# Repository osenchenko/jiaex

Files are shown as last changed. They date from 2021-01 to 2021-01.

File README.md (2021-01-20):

#  JiaEX - split keyboard for extended alphabets.

`assembled-keyboard.stl` - 3d model of assembled keyboard.

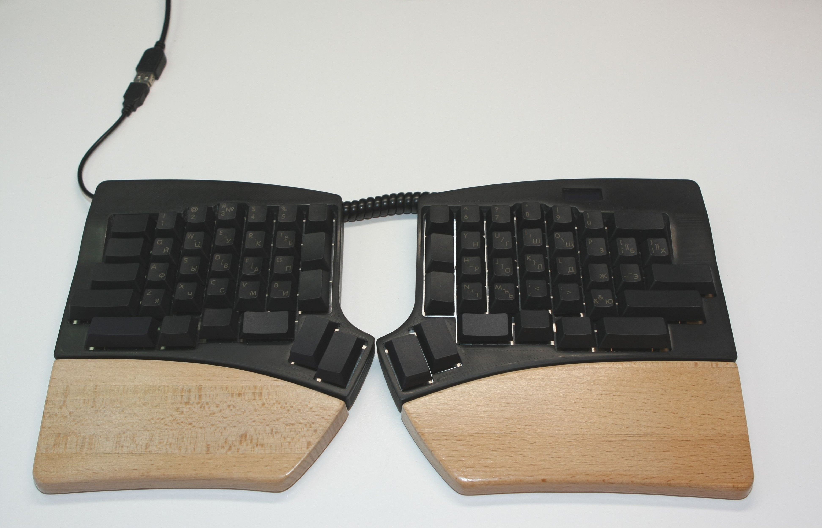
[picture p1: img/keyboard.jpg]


## Features

- enough keys for placing on base layer all letters for extended alphabets (alphabets with more than 26 letters).
- plenty of keys for playing with different variants to find your best setup.
- one keyboard for all operating systems. Switch between settings for different operating systems with a shortcut (currently settings for Linux and Windows are implemented).
- used AT90USB1286 with 128 KB memory. No limits for storing settings.
- wide choice of keycaps. The keyboard is designed for maximum use of keycap sets from standard keyboards. 1.75U keys of thumb cluster and 1.5U vertical keys can be replaced with 1.5U or 1.25U keys in any combination.
- wrist pad is rigidly attached to the keyboard. The keyboard is not intended to be used without a wrist pad.
- the display shows current default layout (for example Linux) and current active layer plus Caps Lock state.
- powered by QMK.

## Layout

[keyboard-layout-editor.com](http://www.keyboard-layout-editor.com/#/gists/80bbde035c246cb868fec8fd4ef6ad40)

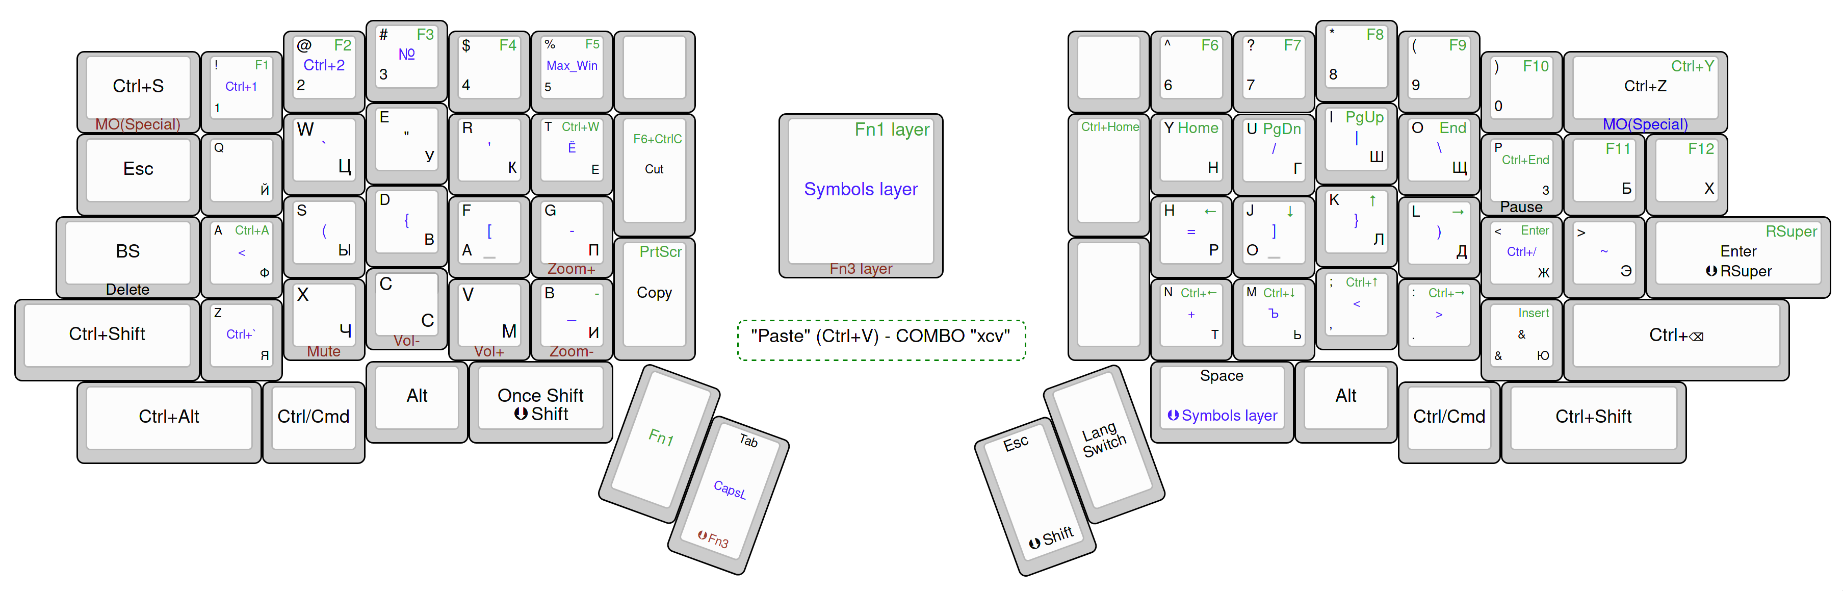
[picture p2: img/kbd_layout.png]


## Build guide

### Folders

- `case` - stl-files for 3d printing case and wrist pads. <br/>Case and wrist pads are designed by Alexander_St enginemojo@gmail.com.
- `datasheets` - datasheets for some used parts
- `firmware` - source files for QMK firmware
- `pcb` - KiCAD source and gerber files for manufacturing PCB.
- `plate` - dxf for laser cutting metal plate.

### Firmware

- install qmk 
- copy folder `jiaex` from `firmware` to `keyboards` folder of qmk installation
- <u>Until pull request [#11487](https://github.com/qmk/qmk_firmware/pull/11487) is not merged in QMK master you must apply this pull request by yourself.</u>
- run `qmk flash -kb jiaex -km default` 

### PCB and Case

Kicad libraries used:

- https://github.com/XenGi/teensy_library

### Bill of materials

| Name | Value | Quantity |
| --- | --- | ---: |
| Microcontroller board | [Teensy ++ 2.0](https://www.pjrc.com/store/teensypp.html) | 2 |
| SMD Diode | 1N4148 [SOD-123] | 68 |
| SMD Resistor 1206 | 30K | 2 |
| SMD Resistor 1206 | 3K | 4 |
| SMD Resistor 1206 | 10K | 1 |
| Jack RJ-22 | [215875-1, Conn RJ-22 F 4 POS 1.02mm Solder RA Thru-Hole 4 Terminal 1 Port Cat 3 T/R](datasheets/Jack_RJ-22.pdf) | 2 |
| OLED display | [0.91 inch OLED Module 128x32, I2C](datasheets/OLED_Module_User_Manual_EN.pdf) | 1 |
| Plug for OLED display | [PLS-4R (DS1022-1x4R)](datasheets/DS1022.pdf) | 1 |
| Key switch | Any Cherry MX compatible | 68 |
| Key stabilyzers | Any Cherry MX compatible, plate mount | 6 |
| 4-wire phone cable with RJ11 (TP-4P4C) jacks. | Max length of cable - 11 cm. | 1 |
| Rubber feet | At your own choice. I use [RF-3004](datasheets/DOC004505728.pdf) | --- |
| Metal plate. Thickness | 1.5 mm | 2 |

### Screws

| Name | Diameter, mm | Length, mm | Image | Quantity | Notes |
| --- | ---: | ---: | --- | ---: | --- |
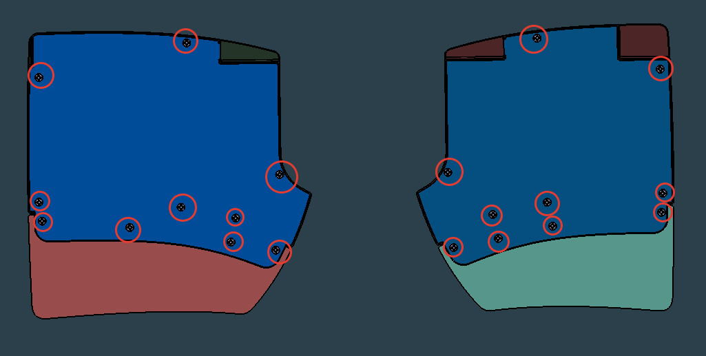
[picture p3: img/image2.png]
| Self-tapping screw for plastic, countersunk head, blunt end, Phillips head, full thread, ART 9090 | 3 | 8..10 |  | 20 | Drill the hole with a 2 mm drill before insert screw. |
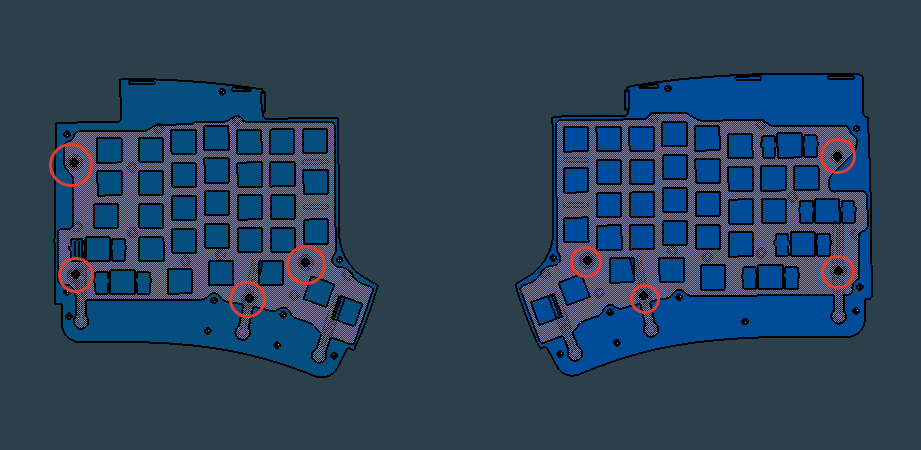
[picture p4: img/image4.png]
| Self-tapping screw DIN 7981 FH (A2) with a blunt end with a half-cylindrical head, head Phillips ST2.2 | 2.2 | 6.5..8 |  | 8 | Drill the hole with a 1.2 mm drill before insert screw. |

## Inspiration

Keyboard is inspired by the following keyboards:

- Jian
- Jiran
- Ultimate Hacking Keyboard
- Ergodox

Layout inspired by ideas of:

- Tonsky https://tonsky.livejournal.com/318571.html (for non-Russian speakers use google translate  in Chrome browser)
- Ultimate Hacking Keyboard
- Optozorax https://github.com/optozorax/moonlander (for non-Russian speakers use google translate in Chrome browser)

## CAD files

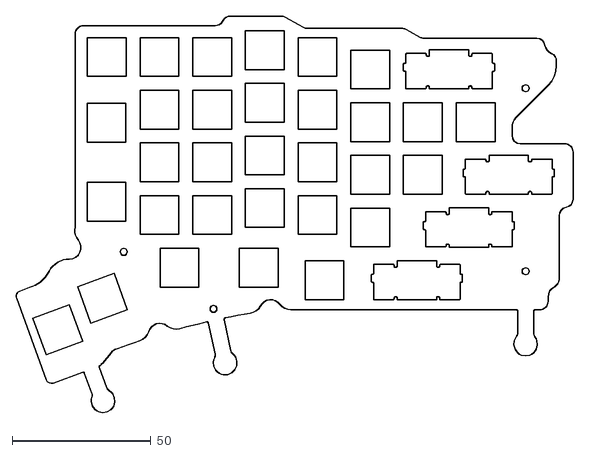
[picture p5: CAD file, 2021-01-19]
plate/RIGHT_Metall_plate.dxf
201.0 x 143.6

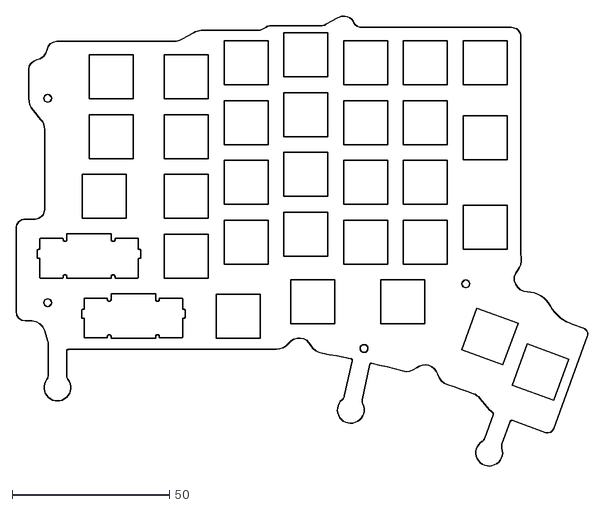
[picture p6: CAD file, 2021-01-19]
plate/LEFT_Metall_plate.dxf
182.0 x 143.6

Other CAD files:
case/left/LEFT_WRIST_PAD.stl
case/right/RIGHT_WRIST_PAD.stl

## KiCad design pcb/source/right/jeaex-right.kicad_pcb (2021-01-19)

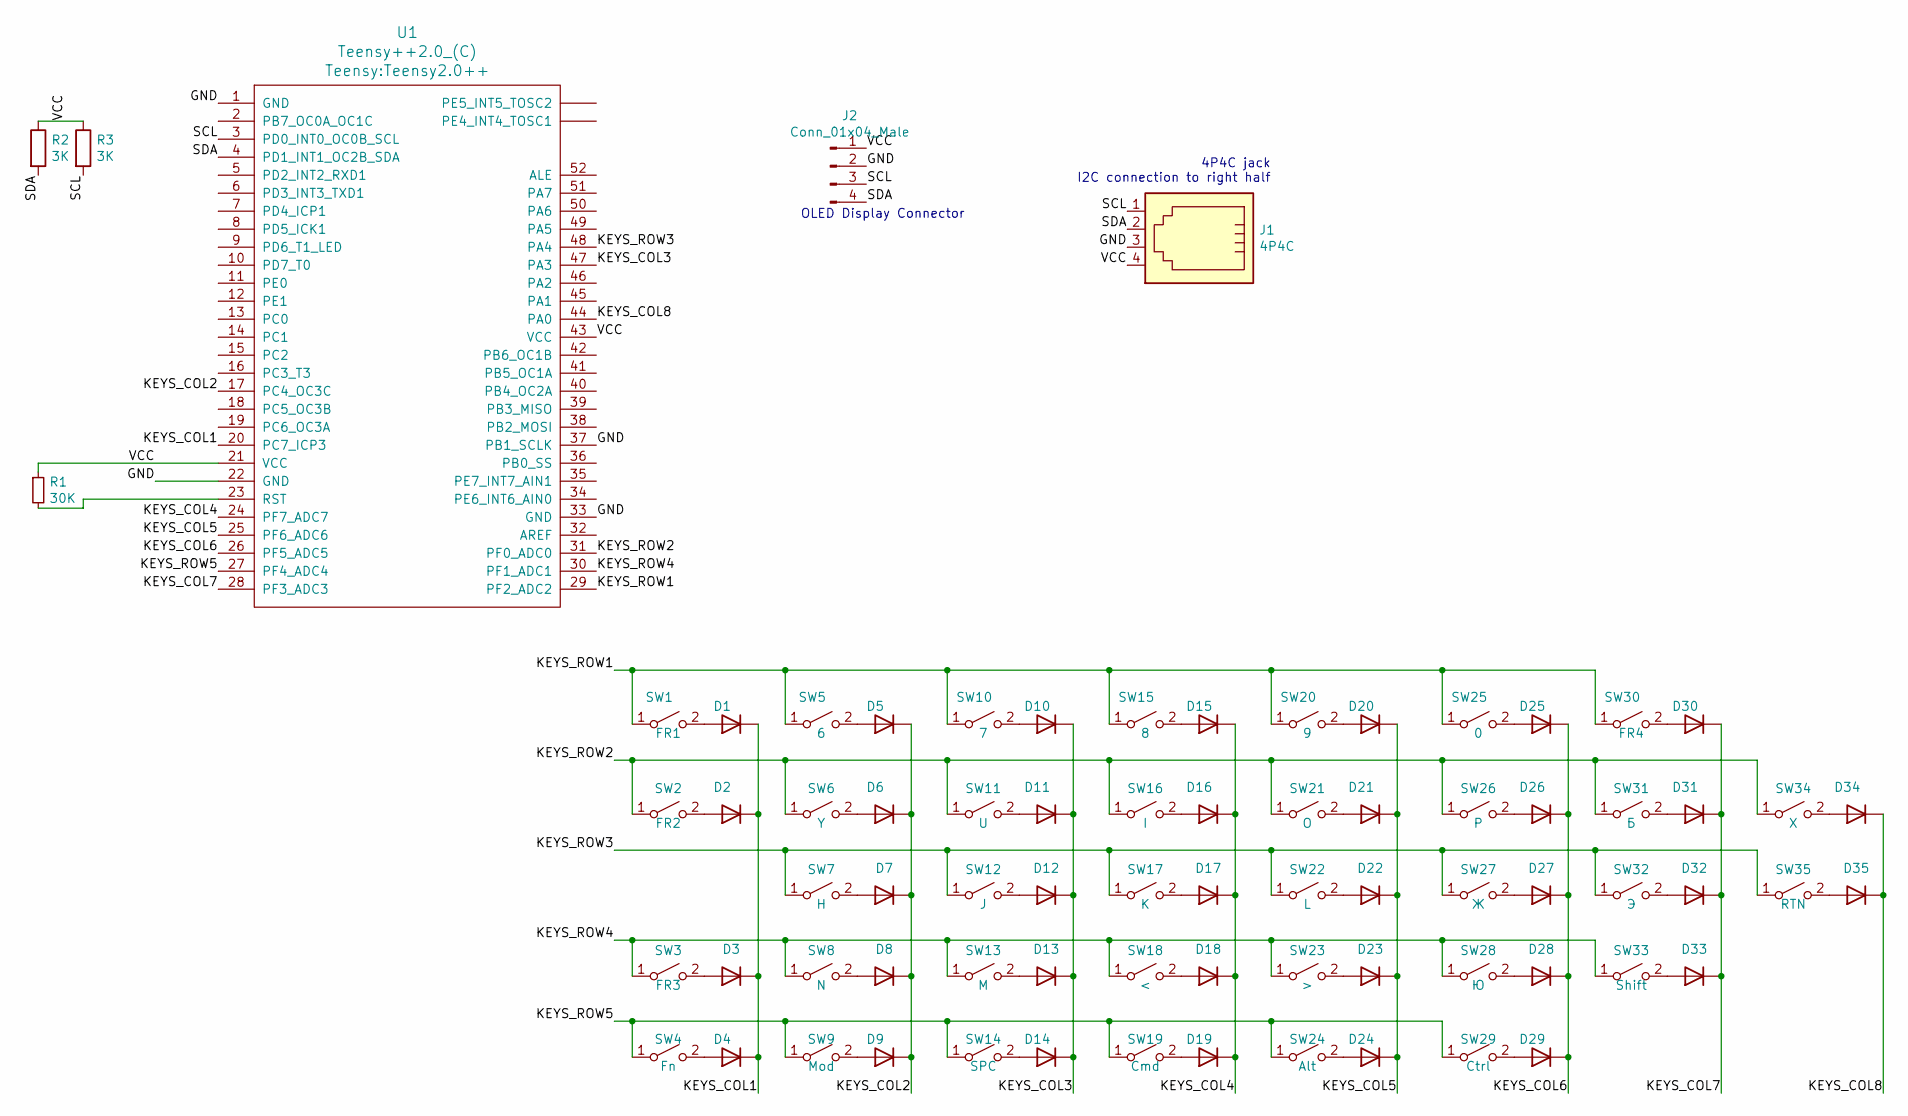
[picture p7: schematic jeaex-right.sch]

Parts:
D1, D2, D3, D4, D5, D6, D7, D8, D9, D10, D11, D12, D13, D14, D15, D16, D17, D18, D19, D20, D21, D22, D23, D24, D25, D26, D27, D28, D29, D30, D31, D32, D33, D34, D35: 1N4148W; D_SOD-123
J1: 4P4C; 4P4C_Jack_0955012441
J2: Conn_01x04_Male; PinHeader_1x04_P2.54mm_Vertical
R1: 30K; R_1206_3216Metric_Pad1.30x1.75mm_HandSolder
R2, R3: 3K; R_1206_3216Metric_Pad1.30x1.75mm_HandSolder
SW1: FR1; SW_Cherry_MX_1.00u_Plate
SW2: FR2; SW_Cherry_MX_1.50u_Plate
SW3: FR3; SW_Cherry_MX_1.50u_Plate
SW4: Fn; SW_Cherry_MX_1.75u_Plate
SW5: 6; SW_Cherry_MX_1.00u_Plate
SW6: Y; SW_Cherry_MX_1.00u_Plate
SW7: H; SW_Cherry_MX_1.00u_Plate
SW8: N; SW_Cherry_MX_1.00u_Plate
SW9: Mod; SW_Cherry_MX_1.75u_Plate
SW10: 7; SW_Cherry_MX_1.00u_Plate
SW11: U; SW_Cherry_MX_1.00u_Plate
SW12: J; SW_Cherry_MX_1.00u_Plate
SW13: M; SW_Cherry_MX_1.00u_Plate
SW14: SPC; SW_Cherry_MX_1.75u_Plate
SW15: 8; SW_Cherry_MX_1.00u_Plate
SW16: I; SW_Cherry_MX_1.00u_Plate
SW17: K; SW_Cherry_MX_1.00u_Plate
SW18: <; SW_Cherry_MX_1.00u_Plate
SW19: Cmd; SW_Cherry_MX_1.25u_Plate
SW20: 9; SW_Cherry_MX_1.00u_Plate
SW21: O; SW_Cherry_MX_1.00u_Plate
SW22: L; SW_Cherry_MX_1.00u_Plate
SW23: >; SW_Cherry_MX_1.00u_Plate
SW24: Alt; SW_Cherry_MX_1.25u_Plate
SW25: 0; SW_Cherry_MX_1.00u_Plate
SW26: P; SW_Cherry_MX_1.00u_Plate
SW27: Ж; SW_Cherry_MX_1.00u_Plate
SW28: Ю; SW_Cherry_MX_1.00u_Plate
SW29: Ctrl; SW_Cherry_MX_2.25u_Plate
SW30: FR4; SW_Cherry_MX_2.00u_Plate
SW31: Б; SW_Cherry_MX_1.00u_Plate
SW32: Э; SW_Cherry_MX_1.00u_Plate
SW33: Shift; SW_Cherry_MX_2.75u_Plate
SW34: Х; SW_Cherry_MX_1.00u_Plate
SW35: RTN; SW_Cherry_MX_2.25u_Plate
U1: Teensy++2.0_(C); Teensy2.0++

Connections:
/GND: J1.3, J2.2, U1.1 (GND), U1.22 (GND), U1.33 (GND), U1.37 (PB1_SCLK)
/KEYS_COL1: D1.1 (K), D2.1 (K), D3.1 (K), D4.1 (K), U1.20 (PC7_ICP3)
/KEYS_COL2: D5.1 (K), D6.1 (K), D7.1 (K), D8.1 (K), D9.1 (K), U1.17 (PC4_OC3C)
/KEYS_COL3: D10.1 (K), D11.1 (K), D12.1 (K), D13.1 (K), D14.1 (K), U1.47 (PA3)
/KEYS_COL4: D15.1 (K), D16.1 (K), D17.1 (K), D18.1 (K), D19.1 (K), U1.24 (PF7_ADC7)
/KEYS_COL5: D20.1 (K), D21.1 (K), D22.1 (K), D23.1 (K), D24.1 (K), U1.25 (PF6_ADC6)
/KEYS_COL6: D25.1 (K), D26.1 (K), D27.1 (K), D28.1 (K), D29.1 (K), U1.26 (PF5_ADC5)
/KEYS_COL7: D30.1 (K), D31.1 (K), D32.1 (K), D33.1 (K), U1.28 (PF3_ADC3)
/KEYS_COL8: D34.1 (K), D35.1 (K), U1.44 (PA0)
/KEYS_ROW1: SW1.1 (A), SW5.1 (A), SW10.1 (A), SW15.1 (A), SW20.1 (A), SW25.1 (A), SW30.1 (A), U1.29 (PF2_ADC2)
/KEYS_ROW2: SW2.1 (A), SW6.1 (A), SW11.1 (A), SW16.1 (A), SW21.1 (A), SW26.1 (A), SW31.1 (A), SW34.1 (A), U1.31 (PF0_ADC0)
/KEYS_ROW3: SW7.1 (A), SW12.1 (A), SW17.1 (A), SW22.1 (A), SW27.1 (A), SW32.1 (A), SW35.1 (A), U1.48 (PA4)
/KEYS_ROW4: SW3.1 (A), SW8.1 (A), SW13.1 (A), SW18.1 (A), SW23.1 (A), SW28.1 (A), SW33.1 (A), U1.30 (PF1_ADC1)
/KEYS_ROW5: SW4.1 (A), SW9.1 (A), SW14.1 (A), SW19.1 (A), SW24.1 (A), SW29.1 (A), U1.27 (PF4_ADC4)
/SCL: J1.1, J2.3, R3.2, U1.3 (PD0_INT0_OC0B_SCL)
/SDA: J1.2, J2.4, R2.2, U1.4 (PD1_INT1_OC2B_SDA)
/VCC: J1.4, J2.1, R1.1, R2.1, R3.1, U1.21 (VCC), U1.43 (VCC)
unnamed: D1.2 (A), SW1.2 (B)
unnamed: D2.2 (A), SW2.2 (B)
unnamed: D3.2 (A), SW3.2 (B)
unnamed: D4.2 (A), SW4.2 (B)
unnamed: D5.2 (A), SW5.2 (B)
unnamed: D6.2 (A), SW6.2 (B)
unnamed: D7.2 (A), SW7.2 (B)
unnamed: D8.2 (A), SW8.2 (B)
unnamed: D9.2 (A), SW9.2 (B)
unnamed: D10.2 (A), SW10.2 (B)
unnamed: D11.2 (A), SW11.2 (B)
unnamed: D12.2 (A), SW12.2 (B)
unnamed: D13.2 (A), SW13.2 (B)
unnamed: D14.2 (A), SW14.2 (B)
unnamed: D15.2 (A), SW15.2 (B)
unnamed: D16.2 (A), SW16.2 (B)
unnamed: D17.2 (A), SW17.2 (B)
unnamed: D18.2 (A), SW18.2 (B)
unnamed: D19.2 (A), SW19.2 (B)
unnamed: D20.2 (A), SW20.2 (B)
unnamed: D21.2 (A), SW21.2 (B)
unnamed: D22.2 (A), SW22.2 (B)
unnamed: D23.2 (A), SW23.2 (B)
unnamed: D24.2 (A), SW24.2 (B)
unnamed: D25.2 (A), SW25.2 (B)
unnamed: D26.2 (A), SW26.2 (B)
unnamed: D27.2 (A), SW27.2 (B)
unnamed: D28.2 (A), SW28.2 (B)
unnamed: D29.2 (A), SW29.2 (B)
unnamed: D30.2 (A), SW30.2 (B)
unnamed: D31.2 (A), SW31.2 (B)
unnamed: D32.2 (A), SW32.2 (B)
unnamed: D33.2 (A), SW33.2 (B)
unnamed: D34.2 (A), SW34.2 (B)
unnamed: D35.2 (A), SW35.2 (B)
unnamed: R1.2, U1.23 (RST)

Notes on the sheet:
4P4C jack I2C connection to right half
OLED Display Connector

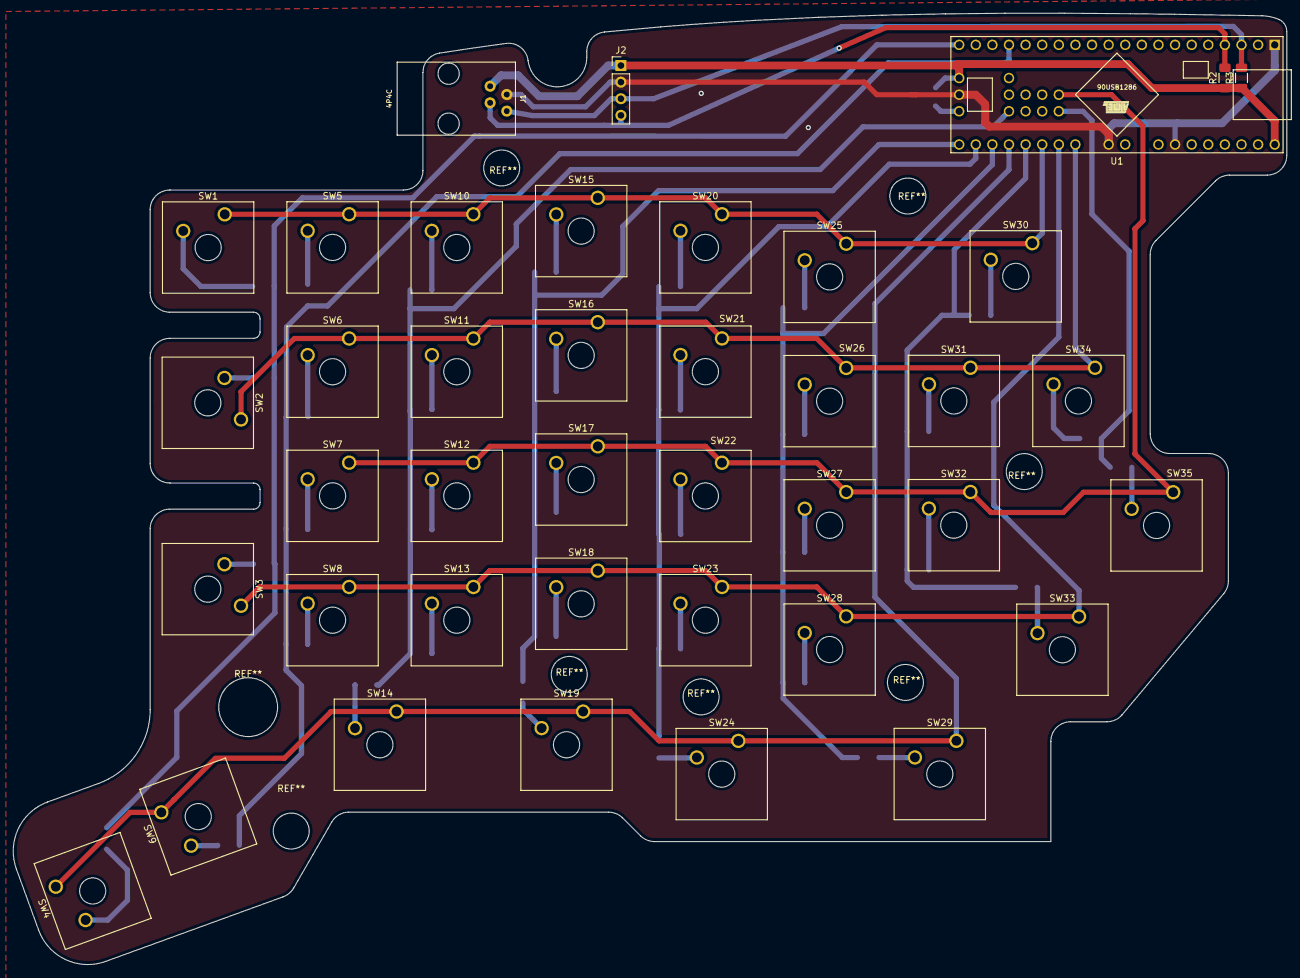
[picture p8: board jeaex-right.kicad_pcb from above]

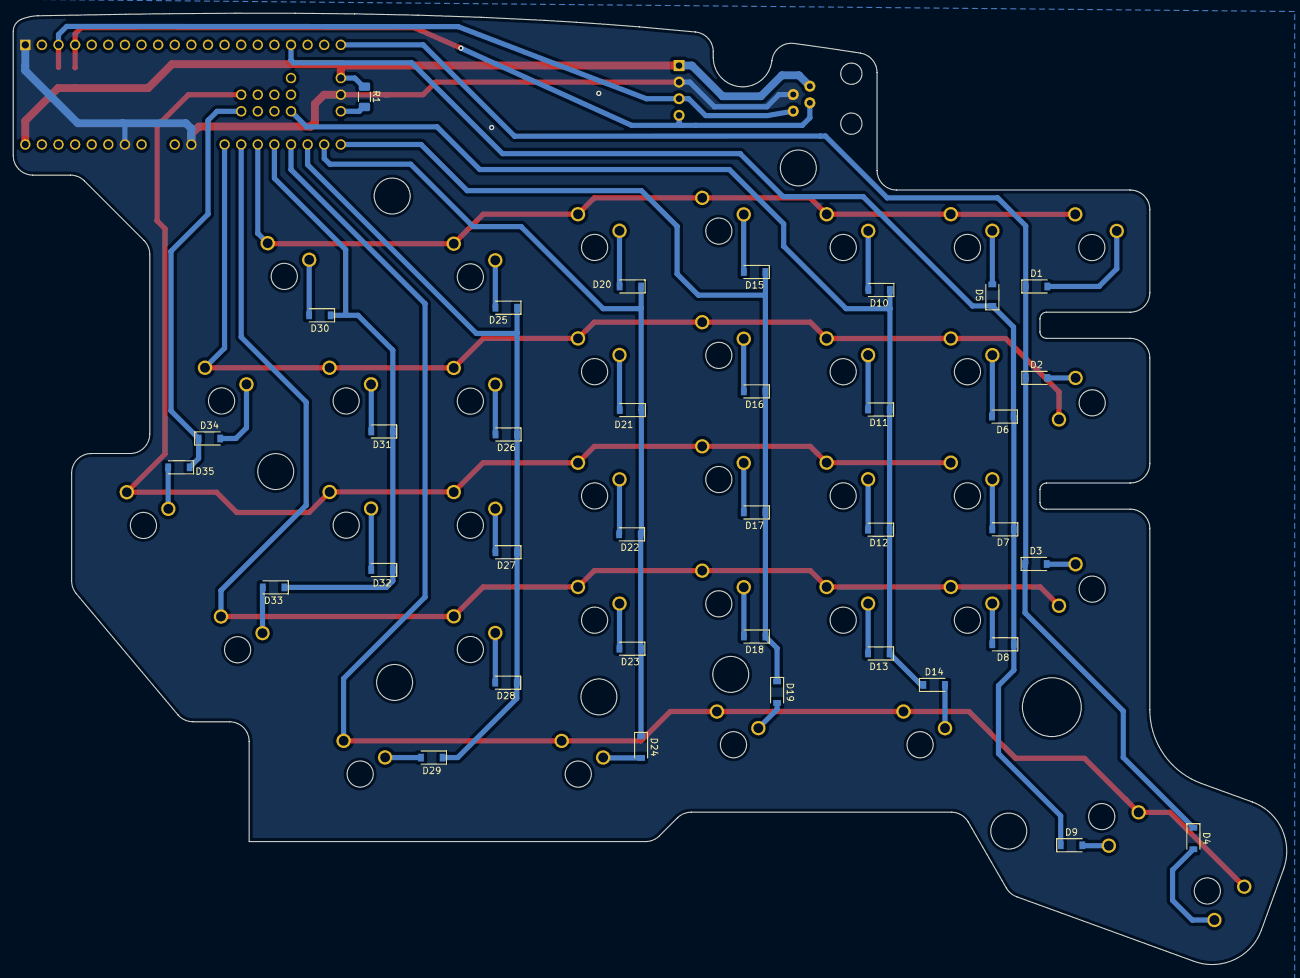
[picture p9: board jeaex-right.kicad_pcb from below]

Board: 2 copper layers, 194.8 x 145.5 mm, 76 parts (36 on the bottom side), 53 nets.

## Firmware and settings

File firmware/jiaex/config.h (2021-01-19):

/*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
You should have received a copy of the GNU General Public License
along with this program.  If not, see <http://www.gnu.org/licenses/>.
*/

#pragma once

#include "config_common.h"

/* USB Device descriptor parameter */
#define VENDOR_ID 0x1209
#define PRODUCT_ID 0x3735
#define DEVICE_VER 0x0001
#define MANUFACTURER Oleg Senchenko
#define PRODUCT JiaEX

/* key matrix size */
// Rows are doubled-up
#define MATRIX_ROWS 10
#define MATRIX_COLS 8

// wiring of each half
#define MATRIX_ROW_PINS \
    { D5, C1, D3, D6, C2 }
#define MATRIX_COL_PINS \
    { D2, D4, E0, C3, C6, C5, C7 }

#define MATRIX_ROW_PINS_RIGHT \
    { F2, F0, A4, F1, F4 }

#define MATRIX_COL_PINS_RIGHT \
    { C7, C4, A3, F7, F6, F5, F3, A0 }

/* COL2ROW or ROW2COL */
#define DIODE_DIRECTION ROW2COL

#define MASTER_LEFT
#define SPLIT_HAND_PIN B1
#define USE_I2C
#define F_SCL 400000UL  // SCL frequency
#define SLAVE_I2C_ADDRESS 0x32

#define SPLIT_USB_DETECT
#define SPLIT_USB_TIMEOUT 2000
#define SPLIT_USB_TIMEOUT_POLL 10

/* Set 0 if debouncing isn't needed */
#define DEBOUNCE 5

#define TAPPING_TERM 200
#define TAPPING_TERM_PER_KEY

#define LEADER_TIMEOUT 350
#define LEADER_PER_KEY_TIMING
#define ONESHOT_TIMEOUT 350


#define COMBO_COUNT 4
#define COMBO_TERM 100

// #define DEBUG_MATRIX_SCAN_RATE

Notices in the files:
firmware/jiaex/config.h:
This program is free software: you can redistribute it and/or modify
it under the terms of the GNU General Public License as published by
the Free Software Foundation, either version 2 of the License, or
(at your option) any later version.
